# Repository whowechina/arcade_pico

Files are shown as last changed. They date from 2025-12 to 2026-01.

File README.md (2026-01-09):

# Arcade Pico - An Alternative Switch/Lamp Holder for Arcade Buttons
[点这里可以切换到中文版](README_CN.md)

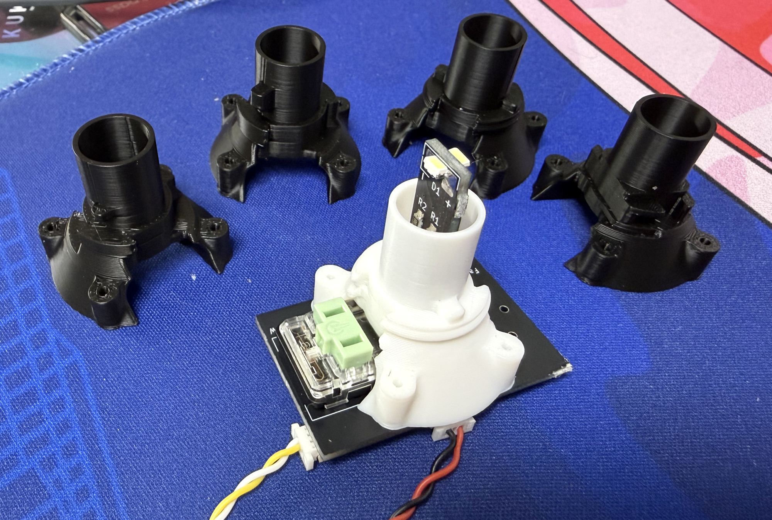
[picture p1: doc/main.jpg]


It's the successor to my sanwa_opt project. With it, you can use regular low-profile keyboard switches (or even optical sensors) on arcade buttons.

## Features
* Compatible with both old Sanwa (push-click) and new Sanwa (twist-lock), Samducksa, and common Chinese buttons;
* Supports mechanical switches, optical sensors, and magnetic switches (`IO Board` required);
* Mechanical switch can be hotswap (Kailh Choc sockets);
* Feel switch and actuation switch can be separated;
* RGB LED support (`IO Board` required);
* FDM 3D-printing friendly.
* Multiple connection options to fit different systems.

## Thanks
Thanks to many respectful guys/companies who made their tools or materials free or open source (KiCad, OnShape, InkScape, Raspberry things).

Special thanks to community projects and developers.
And also these projects:
* RP_Silicon_KiCad: https://github.com/HeadBoffin/RP_Silicon_KiCad

## My Other Projects
You can check out my other cool projects.

                

* Popn Pico: https://github.com/whowechina/popn_pico
* IIDX Pico: https://github.com/whowechina/iidx_pico
* IIDX Teeny: https://github.com/whowechina/iidx_teeny
* Chu Pico: https://github.com/whowechina/chu_pico
* Mai Pico: https://github.com/whowechina/mai_pico
* Diva Pico: https://github.com/whowechina/diva_pico
* AIC Pico: https://github.com/whowechina/aic_pico
* Groove Pico: https://github.com/whowechina/groove_pico
* Geki Pico: https://github.com/whowechina/geki_pico
* Musec Pico: https://github.com/whowechina/musec_pico
* Ju Pico: https://github.com/whowechina/ju_pico
* Bishi Pico: https://github.com/whowechina/bishi_pico
* Nos Pico: https://github.com/whowechina/nos_pico
* Voltex Pico: https://github.com/whowechina/voltex_pico
* Chord Pico: https://github.com/whowechina/chord_pico
* Arcade Pico: https://github.com/whowechina/arcade_pico

## **Disclaimer** ##
I made this project in my personal time with no financial benefit or sponsorship. I will continue to improve the project. I have done my best to ensure that everything is accurate and functional, there's always a chance that mistakes may occur. I cannot be held responsible for any loss of your time or money that may result from using this open source project. Thank you for your understanding.

## About the License
It's CC-NC. So DIY for yourself and for your friend, don't make money from it. And plagiarism that doesn’t even dare to mention the original author is not acceptable. Please note that pooling orders and group buying for raw materials is acceptable.Selling any leftover components at cost (without profit) is also acceptable.

If you're interested in buying from me, or for commercial use, please contact me (Discord, QQ group, Goofish).
* My Discord Invitation: https://discord.gg/M8f2PPQFEA
* QQ Group: 854535476
* Goofish: whowe12345

## Use Cases
### Terminology First
* **`Main Board`** - The original controller board or IO board of your arcade system.
* **`Button Board`** - The PCB that contains the switch and LED daughter board. It's the major part of the Arcade Pico project.
* **`IO Board`** - The optional PCB that converts Hall effect switch signals to digital signals, and bridges regular LED signals to WS2812B RGB LED data signals. It's also part of the Arcade Pico project. It cannot replace your original `Main Board`.
* **`Lamp Holder`** - More accurately, it's a base equipped with both lamp and switch, but commonly referred to as lamp holder.

### Case: Replace the Lamp/Switch Holder without the `IO Board`
It's the most common and easy case. The only thing you need to do is wiring the switch and LED signals from your `Main Board` to the corresponding connectors on the `Button Board`.
You can use mechanical switches or optical sensors, but you can't use magnetic switches or RGB lights.

#### Wiring:
* **SW Out** (SH1.0 3P) on `Button Board` → **Button Input** on `Main Board`
* **LED In** (SH1.0 3P) on `Button Board` ← **Lamp Output** on `Main Board`

### Case: Enjoy the Magnetic Switch or the RGB light with the `IO Board`
With magnetic switch, you can define your trigger and reset distance. With RGB light, you can define your button light color and effect. `IO Board` is required to drive the magnetic switch and RGB light.

#### Wiring:
* Magnetic switch signals
  * **SW Out** (SH1.0 3P) on `Button Board` → **Hall In** (SH1.0 3P) on `IO Board`
  * **Out** (XH2.5 2P) on `IO Board` → **Button Input** on `Main Board`
* RGB LED signals
  * **Lamp Output** on `Main Board` → **Lamp In** (XH2.5 2P) on `IO Board`
  * **LED Out** (SH1.0 3P) on `IO Board` → **LED In** (SH1.0 3P) on `Button Board`
  * **LED Out** (SH1.0 3P) on `Button Board` → **LED In** (SH1.0 3P) on next `Button Board` (if any)
  * **LED Out** (SH1.0 3P) on last `Button Board` → **LED End** (SH1.0 3P) on `IO Board` for power backup.

* You can power the `IO Board` from the `Main Board`'s 5V supply via JST 2P, or directly via Type-C port (USB or power adapter).

#### When `IO Board` is connected to a host computer via Type-C:
  * `IO Board` works as an HID device.  
    So if you're fine with this extra USB cable, you might be able to skip the wiring between the `IO Board` and the `Main Board`. However, some games require the controller to be a single device, so this won't work in those cases.
  * CLI (command line interface) is on USB CDC (serial).
  * The Type-C port is also for firmware update.

### Imagined Case: Interfacing with DJDao PhoenixWAN
This is a theoretical case that probably won't be implemented. If implemented, all that cockamamie wiring between `IO Board` and `Main Board` would be eliminated - they'd simply communicate via UART.

Let's hope this happens someday.

# How to Build
## The Button Board
### Common Part
* The PCB gerber file is `Production/PCB/"arcade_pico_button_*.zip`. The one with `socket` is hotswap (for Choc V1 and V2). I always use JLC (https://www.jlcpcb.com) and Jiepei (https://www.jiepei.com), feel free to use your preferred PCB manufacturer. They may ask if you need half-hole pads for the `Button Board`, just answer "No", it's costy and not necessary.
* 2X 3P SH1.0 horizontal SMD connector on "SW" and "LED In" footprints.
* 1X 3P SH1.0 horizontal SMD connector on "LED Out" footprint, only needed when using WS2812B RGB LED daughter board.

* To connect LEDs:
  * "LED In" connector (+, -) is for regular single color LED signal from your existing `Main Board`.
  * "LED In" and "LED Out" connectors are for daisy-chain when using WS2812B RGB LED daughter board.

### Mechanical Switch
* Use either SW1 or SW2 footprint for Kailh Choc V1/V2 switches.
* Use Kailh Choc low-profile hotswap socket if you choose hotswap PCB version.  
  https://kailhswitch.net/products/kailh-mechnical-keyboard-switches-hot-swap-pcb-socket-diy-for-1350-choc-low-profile-keyboard-switches
* Short the corresponding jumper (sw1 or sw2) to enable the switch.
* You can solder the other switch, but it's only for the feel, so don't short the jumper.

* To connect to controller's `Main Board`:
  * "SW" connector (Out, GND) is for the switch signal;

* This example shows SW1 as the trigger switch, and optional Choc V1 on SW2 is just for the feel.  
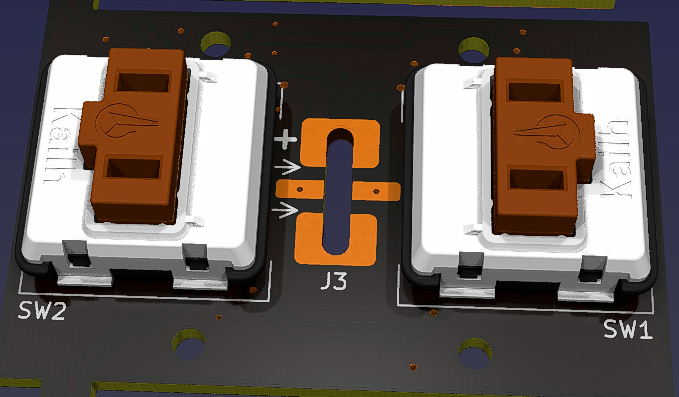
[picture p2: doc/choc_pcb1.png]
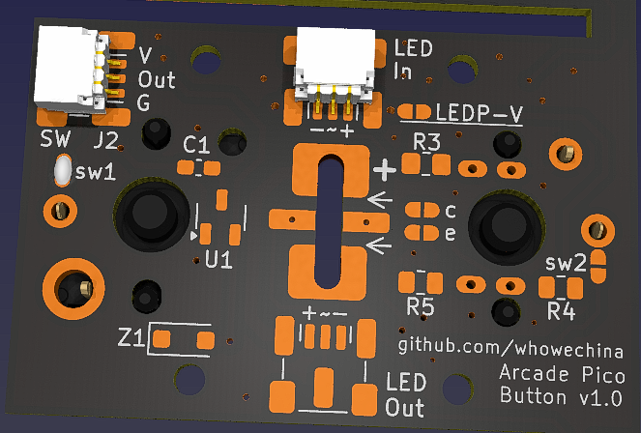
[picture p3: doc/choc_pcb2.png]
   

### Optical Sensor (IR Diode + Phototransistor)
* Solder the IR diode (IR908-7C) and phototransistor (PT908-7C) at proper height;
* Solder R3 (500 ohm for 3.3V supply, 1k ohm for 5V supply);
* Resistors: R4, R5; Jumpers: c, e; Zener: Z1.
  * Low-active logic (most systems are): R4 (0-10 ohm), R5 (2k ohm), short the jumper e by soldering.
  * High-active logic: R4 (2k ohm), R5 (0-10 ohm), short the jumper c.
  * When power supply is 5V but the target system IO is 3.3V, solder Z1 (3.3V SOD-123F Zener diode) to protect the IO pin.
* You can solder a mechanical switch on SW1 footprint for some tactile feel, but don't short the jumper sw1.
* On most systems, LED positive line is a constant 5V or 3.3V power supply, you can borrow that to power the optical sensor - just short the jumper "LEDP-V".

* To connect to controller's `Main Board`:
  * "SW" connector (V, Out, GND) is for the switch signal;

* This example shows a low-active configuration, 5V is borrowed from LED positive line, and optional Choc V1 on SW1 just for the feel.  
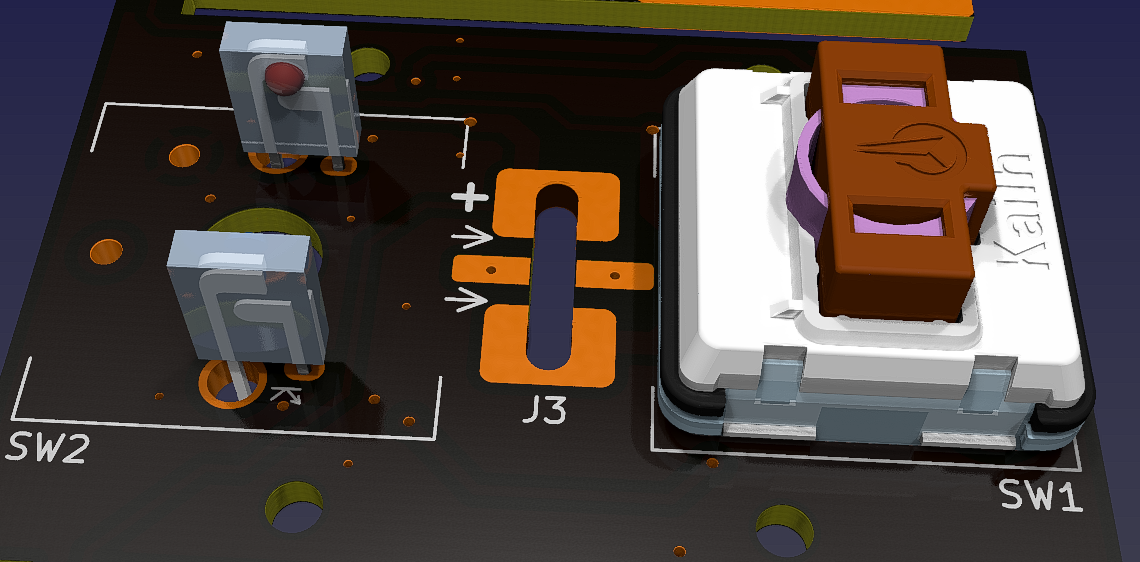
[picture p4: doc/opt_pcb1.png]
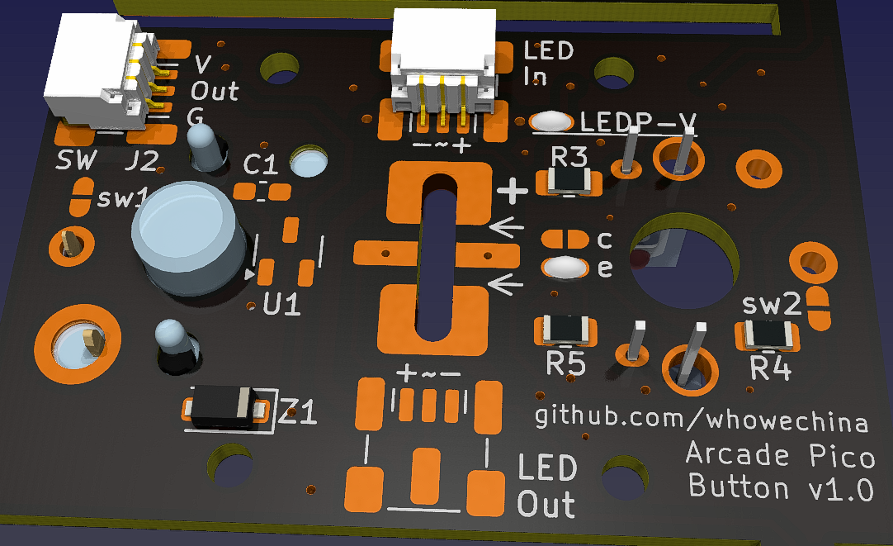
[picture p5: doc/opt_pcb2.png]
   

### Magnetic (Hall Effect) Switch
* Magnetic switch is on SW1 footprint.
* Solder U1 (SS49E SOT23-3) and C1 (0.1uF 0603).
* You can install a mechanical switch on SW2 footprint for some tactile feel, but don't solder the jumper.
* If the Hall effect switch is not mounted tightly, you may need to use some RTV silicone adhesive to secure it.

* This example uses Hall effect switch on SW2 and optional Choc V1 on SW1 just for the feel.  
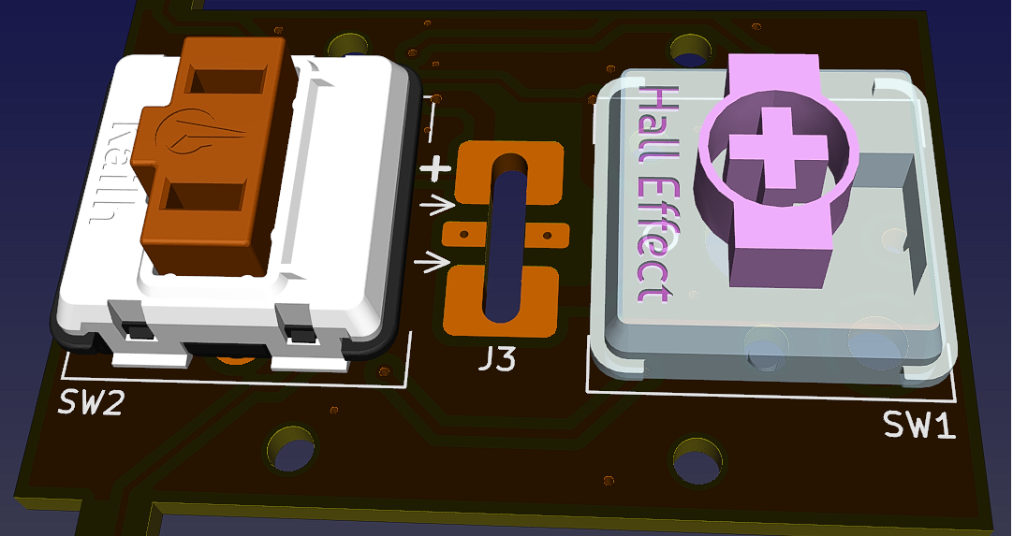
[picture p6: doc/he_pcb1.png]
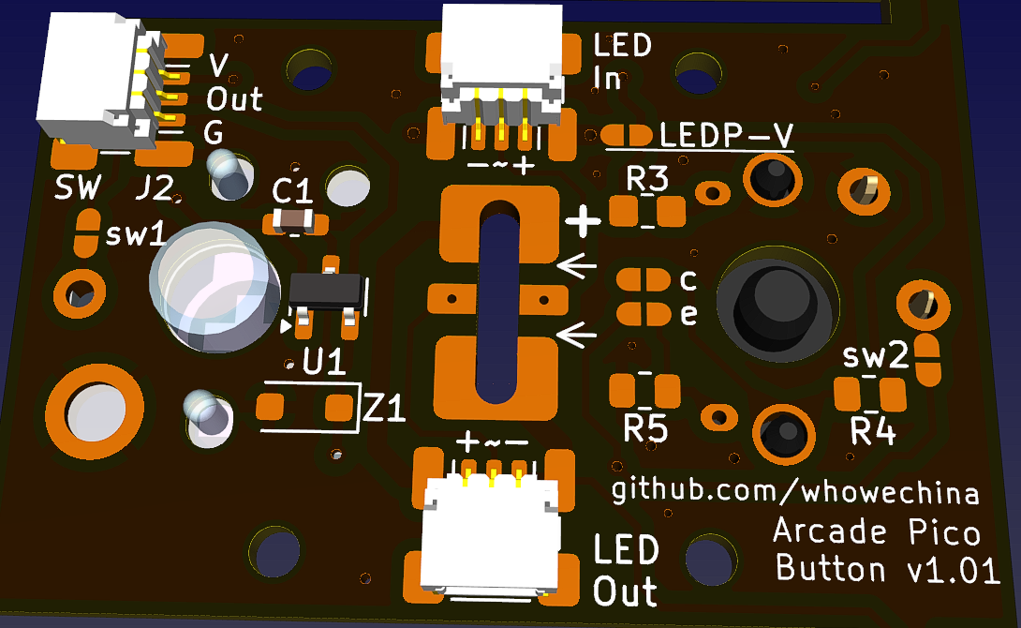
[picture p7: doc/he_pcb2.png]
   

* To connect to controller's `Main Board`:
* "SW" connector (V, Out, G) connects to the **Arcade Pico IO** board. Then the `IO Board` connects to the `Main Board`.

* Note that Arcade Pico `IO Board` is need for this setup.

## The LED Daughter Board
* It is separated from the **Arcade Pico Button** board by snapping or cutting. There're two versions: single-color LED and WS2812B RGB LED. You can choose either one according to your needs.
* After soldering the components, insert the LED daughter board back to the button PCB vertically from the top side. Solder one pin first, so you'll have a chance to adjust the height.
* If it's too low or too high, you won't get even illumination. You can measure the height from your old lamp holder. From my experience with Sanwa, distance from the LED top to the PCB surface is about 37mm.
* When you finish adjusting the height, solder all pins to secure the connection.  
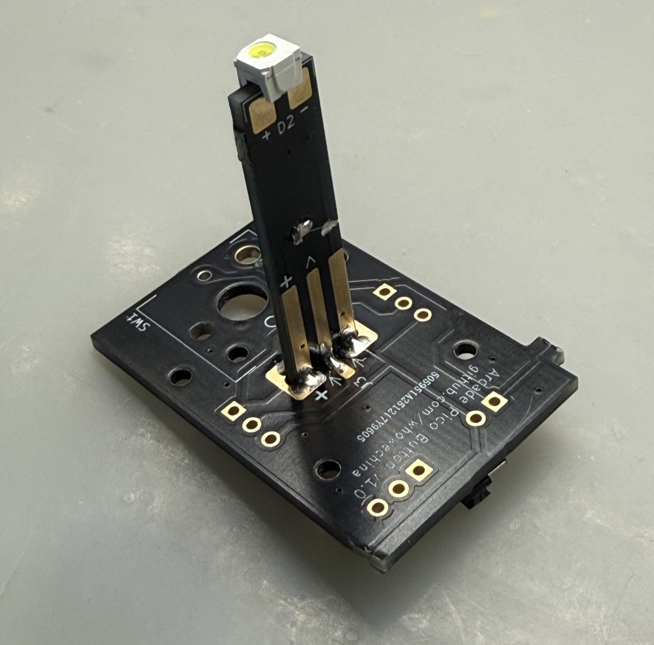
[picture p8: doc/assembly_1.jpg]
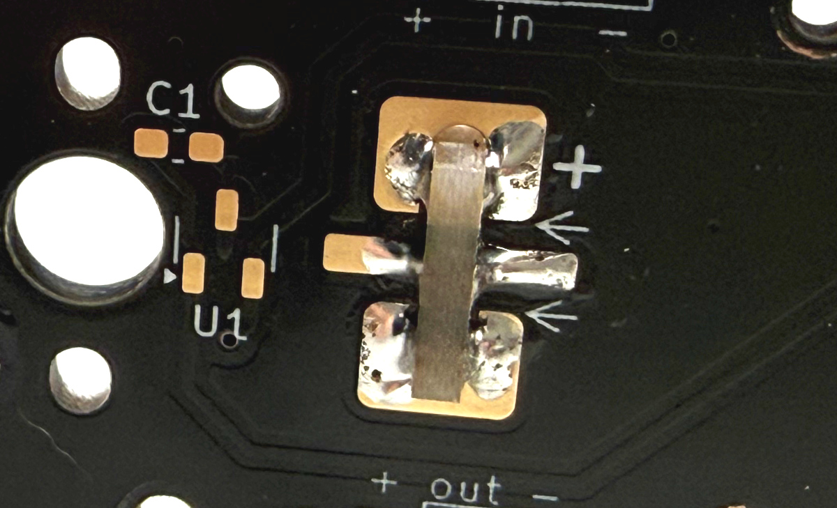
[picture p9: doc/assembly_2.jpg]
 

### Single-color LED Board
* Use high-brightness side emitting LEDs. The footprint is compatible with various packages, such as SMD 4008, SMD 4020, SMD 3014, or even through-hole ones (ones with concave lens are better).
* If you're using SMD LEDs, you can use two of them, one for each side, to get better light distribution.
* They're normally rated for 20mA current. So typically you use 100-220 ohm current resistors (R1 and R2) for 5V supply, or 50-100 ohm for 3.3V supply.
* Here's how it looks after soldered.  
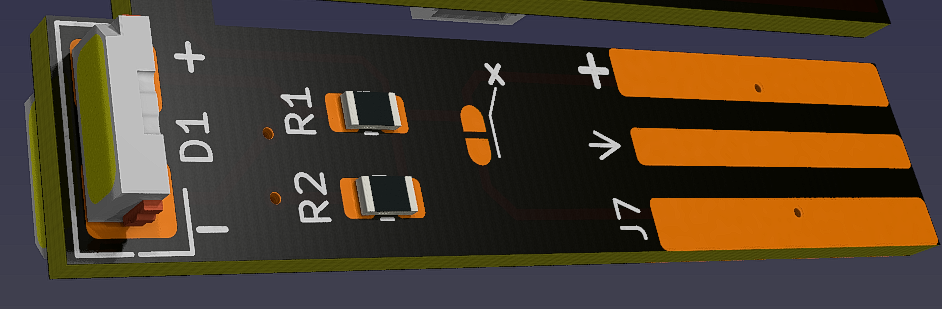
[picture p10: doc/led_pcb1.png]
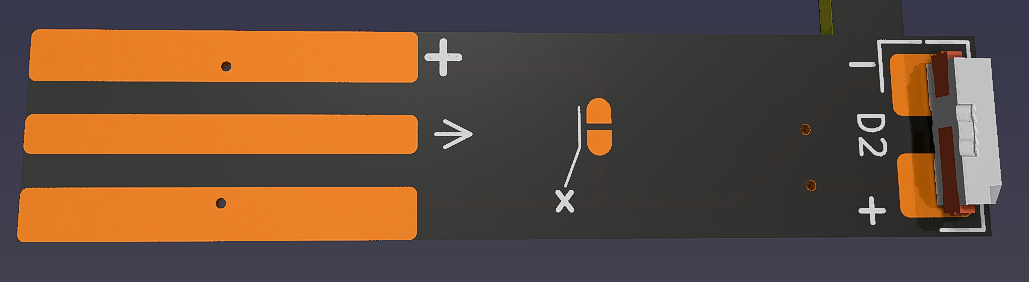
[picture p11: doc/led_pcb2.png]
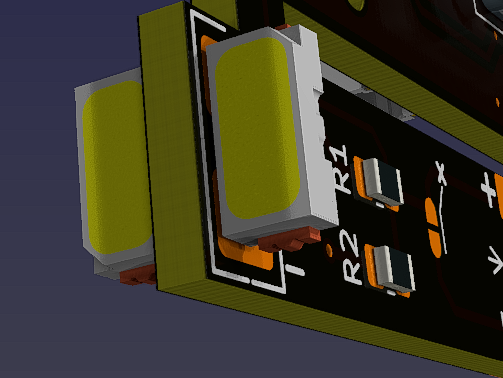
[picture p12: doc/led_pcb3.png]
    
* If the polarity of the LED footprint doesn't match your LED, just cut/break the copper trace right at the "x" mark at **both sides**, and short the jumpers accordingly. This will reverse the polarity.  
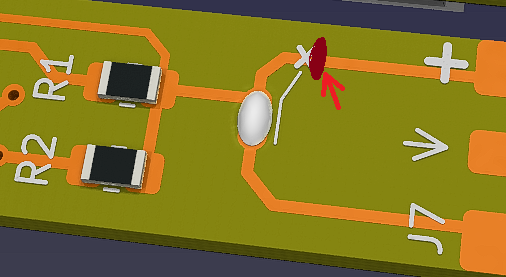
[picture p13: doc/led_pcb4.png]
  

### WS2812B RGB LED Board
* **Arcade Pico `IO Board` is required.**
* Use WS2812B 4020 side emitting RGB LEDs. You can use two of them, one for each side, to get better light distribution.
* 0.1uF 0805 or 0603 capacitor on C2 footprint is highly recommended.
* Here's how it looks after soldered.  
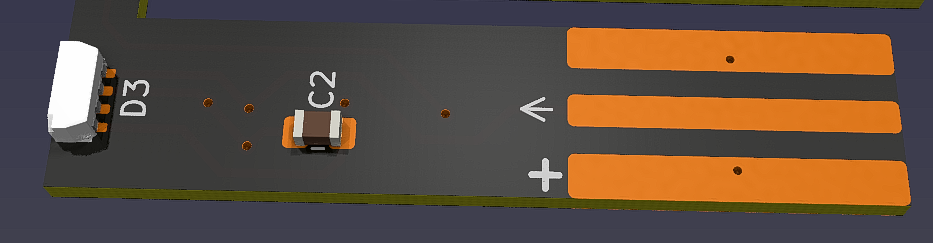
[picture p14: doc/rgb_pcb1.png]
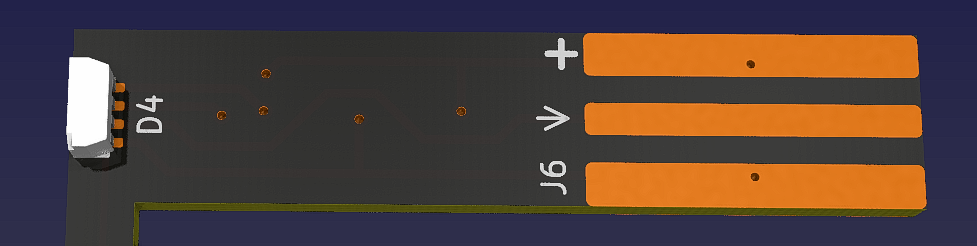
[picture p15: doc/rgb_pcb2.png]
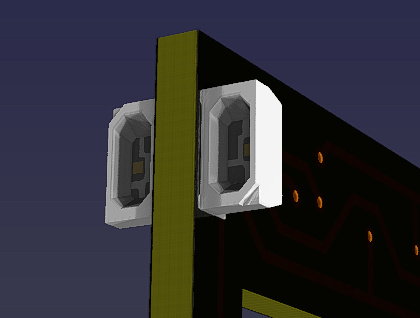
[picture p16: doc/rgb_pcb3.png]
    

## The `IO Board`
* The `IO Board` can convert the analog signals from Hall effect switches into digital signals for your main controller board. It can also bridge traditional LED bulb signals to WS2812B RGB LED data signals.
* If you don't need one or both of these functions, just skip the corresponding components.

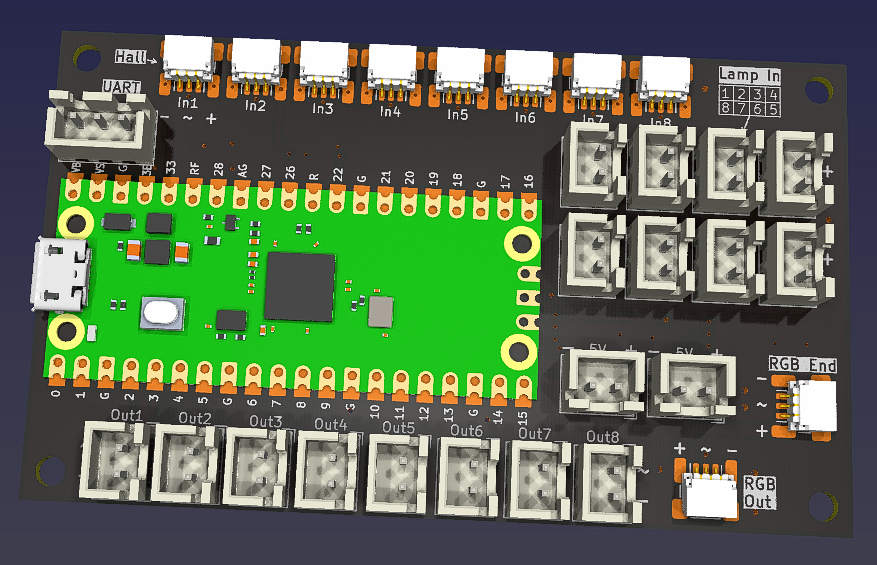
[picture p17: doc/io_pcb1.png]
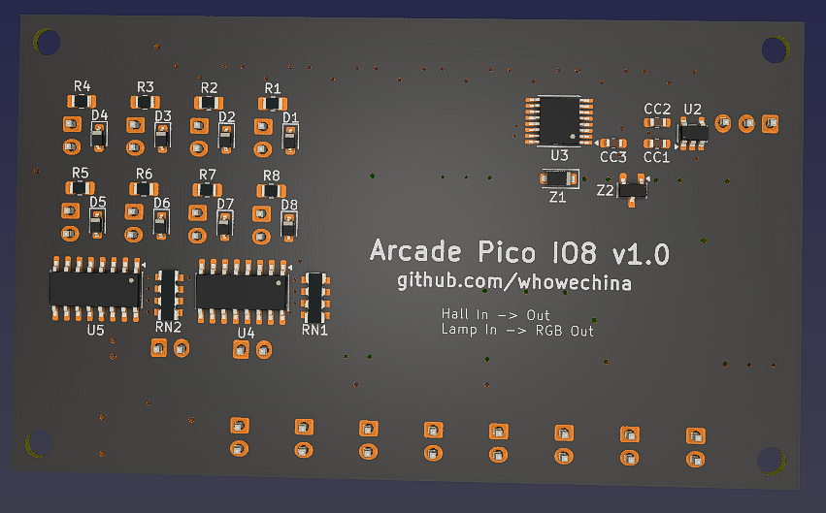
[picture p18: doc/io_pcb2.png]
 

### Common Parts
* 1x Raspberry Pi Pico.  
  https://www.raspberrypi.com/products/raspberry-pi-pico
* 2x 2P JST XH2.54 or XH2.5 vertical connectors, for 5V power input.
* 1x 3P JST XH2.54 or XH2.5 vertical connector for UART, optional for future use.

### Components for Hall Effect Switch
* 1x ADG708BRUZ, 8 to 1 analog switch, in TSSOP-16 (U3).
* 1x LP5907MFX-4.5 or TPS7A2042PDBVR LDO, in SOT23-5 (U2), see next line.
* 1x LM4040 shunt voltage reference in SOT23-3 (Z2), 2.0~2.1V (for 4.2V LDO) or 2.2~2.5V (for 4.5V LDO).
* 1x 3.3V Zener diode, in SOD-123 or SOD-123F, such as BZT52H-C3V3 (Z1).
* 3x 0.1uF 0603 capacitors (CC1, CC2, CC3).
* 8x 3P SH1.0 horizontal SMD connectors (In1~In8), for connecting up to 8 Hall effect `Button Board`s.
* 8x 2P JST XH2.54 or XH2.5 vertical connectors (Out1~Out8), for connecting to the main controller board.

### Components for RGB LED
* 8x 220ohm 0603 resistors (R1~R8), for optical isolator current limiting. If your light is 12V, use 1kohm 0805 resistors instead.
* 8x 1N4148 SOD-323 diodes (D1~D8), to protect from reverse voltage, only needed for 12V light input.
* 2X PC847 or compatible quad optical isolators (U4, U5), in SOP-16.
* 2x 0805 x 4 5.1K 8P4R resistor arrays (RN1, RN2), if they're not available, use 8x individual 5.1K 0603 resistors instead.
* 2x 3P SH1.0 horizontal SMD connectors (LED Out and LED End), to connect to the `Button Board` equipped with WS2812B RGB LED daughter board.
* 8x 2P JST XH2.54 or XH2.5 vertical connectors (Lamp In 1~8), for connecting to the main controller board's LED signal.

## Notes on PCB and Electronics
### Things You May **Need** to Tinker with
* Here's how you calculate the LED current limiter, it also applies to the IR emitter diode of the optical isolator:
  * R = (V_supply - V_F) / I
  * V_F for single color LED is usually around 3V, V_F for IR emitter is usually around 1.3V.
  * I for single color LED is usually 10-20mA, I for IR emitter is practically 1-10mA.
* Here's how you calculate the pull-up or pull-down resistor for phototransistor (the one on the `Button Board` and the one inside the optical isolator):
  * R >= V_supply / I_C
  * It's difficult to estimate the I_C (collector current) of the phototransistor, so just assume it's around 1mA.
  * So on a 3.3V power supply, R >= 3.3V / 1mA = 3.3K ohm, You can use a 3.3K or 3.9K ohm resistor.
  * You may need to adjust the resistor value according to your actual setup.

### Things You May **Want** to Tinker with
* For the "feel switch", choose clicky ones, Choc V1 and Choc V2 both have some clikcy options. If you find other low-profile mechanical switches which fit in the footprint, you can try them too.
* When Hall effect switch and the "feel" switch is both installed, spring force adds up, you may want to use a lighter spring for both of them. You can choose light force switches, or you can change the spring inside them.

## The Holder Body
* Use any FDM printer to print the body.
  * Material: PLA, PETG, ABS, you name it.
  * Layer Height: 0.2mm is recommended.
  * Infill: 20% is enough.
  * Walls: 2-4 perimeters.
  * Support: Yes, tree support.

* Files are in the "Production/3DPrint" folder.
  * `Sanwa_push.stl` - old style Sanwa lamp holder (push-click type).
  * `Sanwa_twist.stl` - new style Sanwa lamp holder (twist-lock type).
  * `Samducksa.stl` - Samducksa lamp holder.
  * `Chinese.stl` - common Chinese button lamp holder.

* Use M2\*6mm screws to secure the PCB to the button.

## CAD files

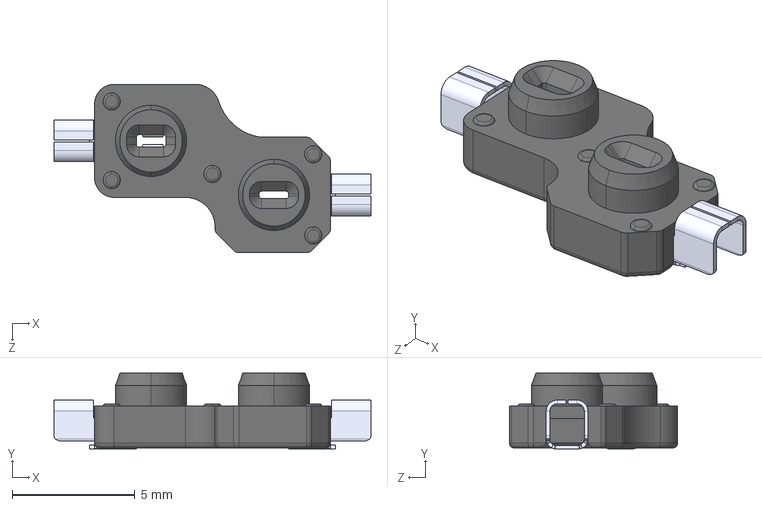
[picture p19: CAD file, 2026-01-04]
PCB/button_dip_led/3dmodels/PG1350-socket.STEP
12.9 x 3.09 x 6.85 mm
pin x 2
socket

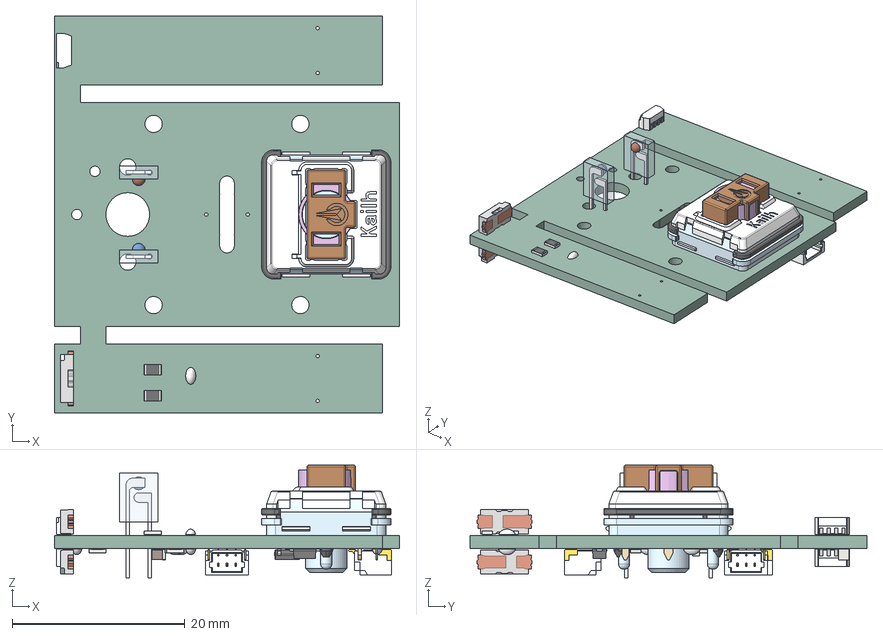
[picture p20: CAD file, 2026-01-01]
PCB/button_dip_led/button_pcb_v1.0.step
40.0 x 46.0 x 13.1 mm
LUXEON_3014 x 2
User Library-WS2812-4020 x 2
SW_Kailh_Choc_V1
Kailh_PG1352 x 3
Lens
LeadA
LeadB
LensPT
Mirrored LeadA
Mirrored LeadB
SolderJump x 7
R_0805_2012Metric x 5
SM3B-SRSS-TB x 3
C_0603_1608Metric
SOT-23-3
C_0805_2012Metric
D_SOD-123F
button_PCB

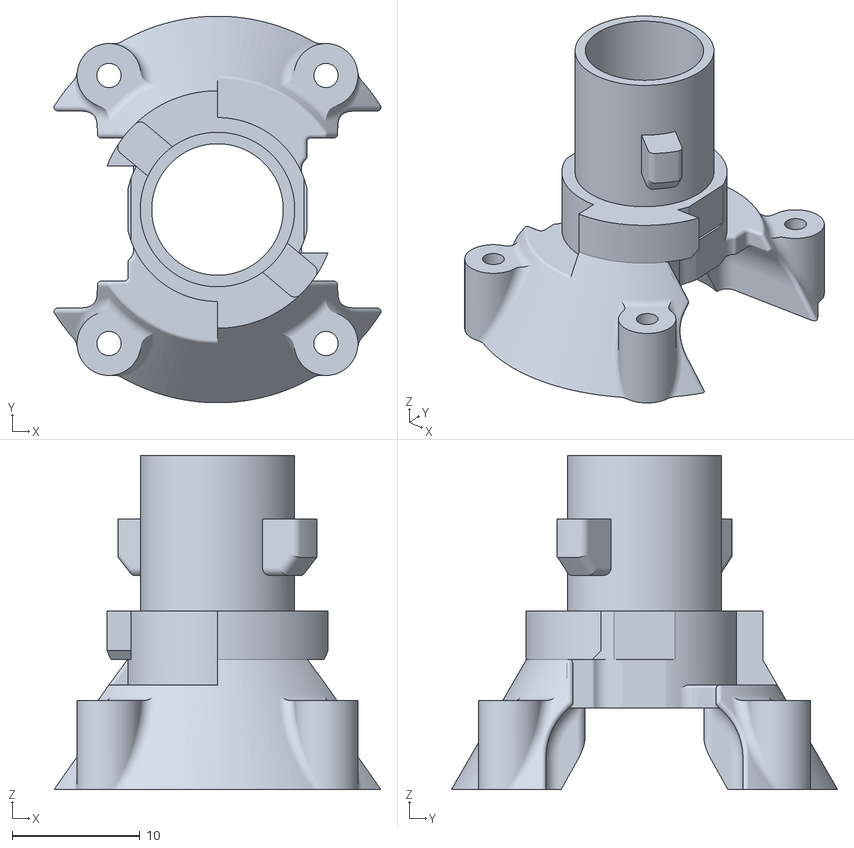
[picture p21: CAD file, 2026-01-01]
Production/3DPrint/Sanwa_twist.stl
25.6 x 30.3 x 26.2

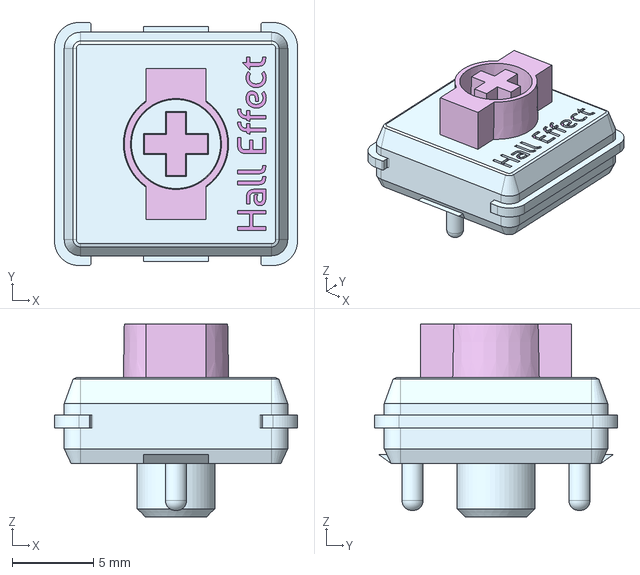
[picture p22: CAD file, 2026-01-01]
PCB/button_dip_led/3dmodels/HE_PG1353.step
15.0 x 15.0 x 11.9 mm

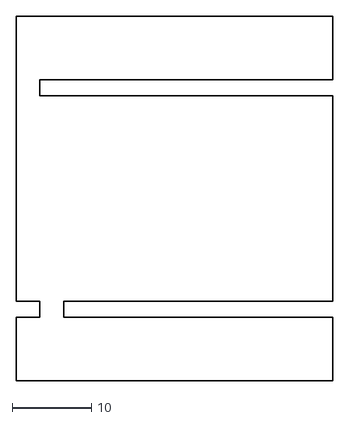
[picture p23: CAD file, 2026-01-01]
PCB/button_dip_led/Arcade Pico - PCB EdgeCut.dxf
40.0 x 46.0

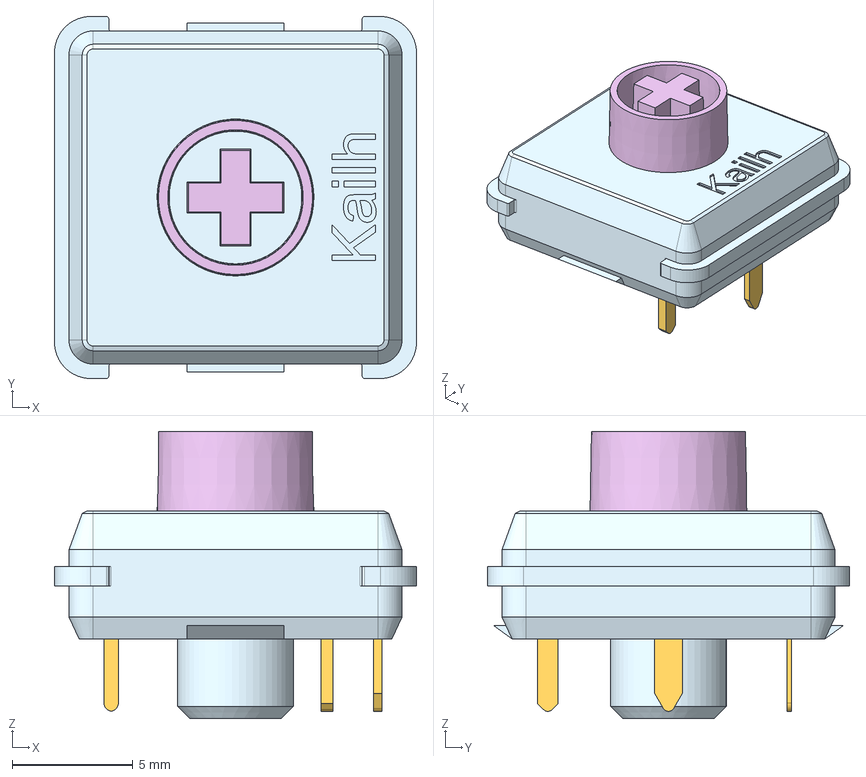
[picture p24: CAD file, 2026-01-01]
PCB/button_dip_led/3dmodels/Kailh_PG1353.STEP
15.0 x 15.0 x 11.9 mm

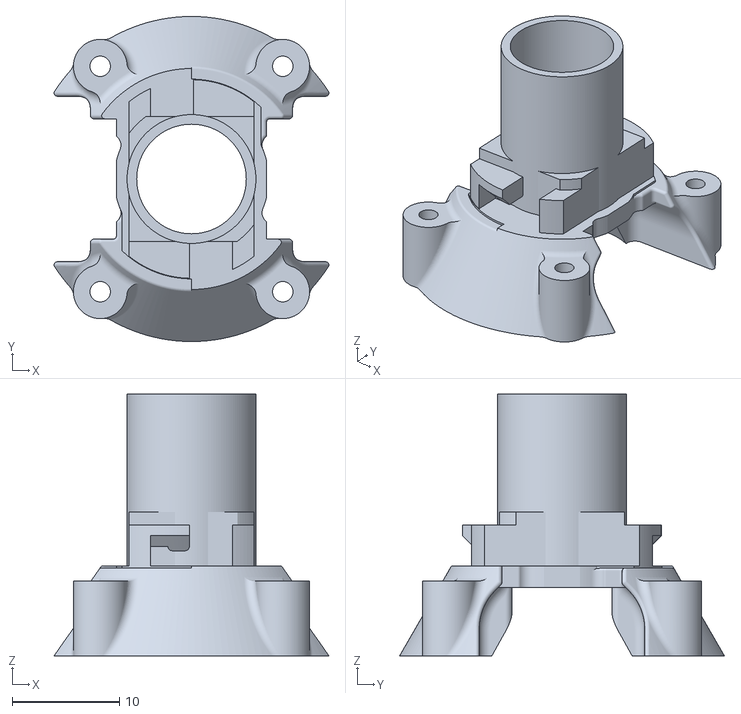
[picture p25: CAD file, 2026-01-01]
Production/3DPrint/Chinese.stl
25.6 x 30.3 x 24.4

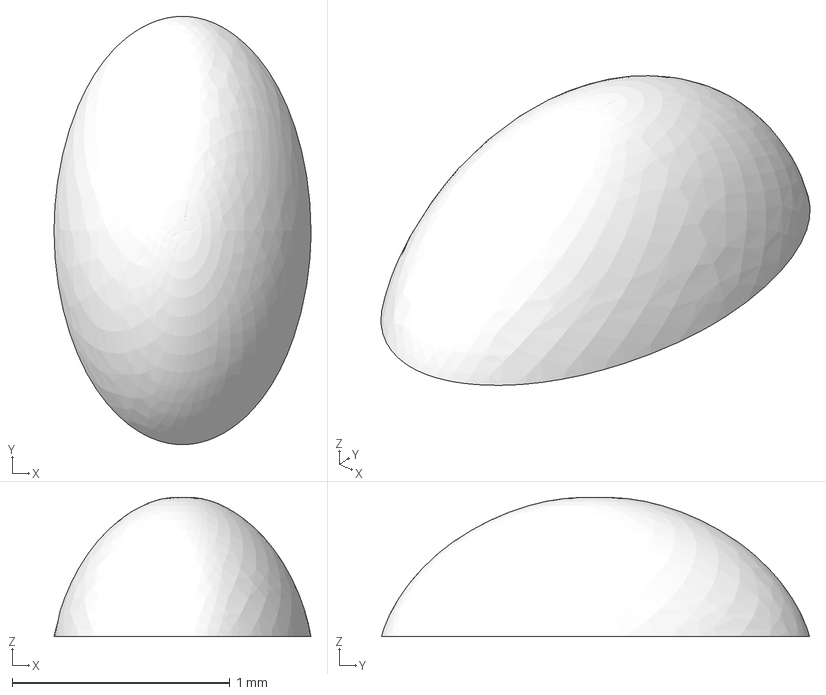
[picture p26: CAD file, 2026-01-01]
PCB/button_dip_led/3dmodels/SolderJump.step
1.18 x 1.97 x 0.64 mm

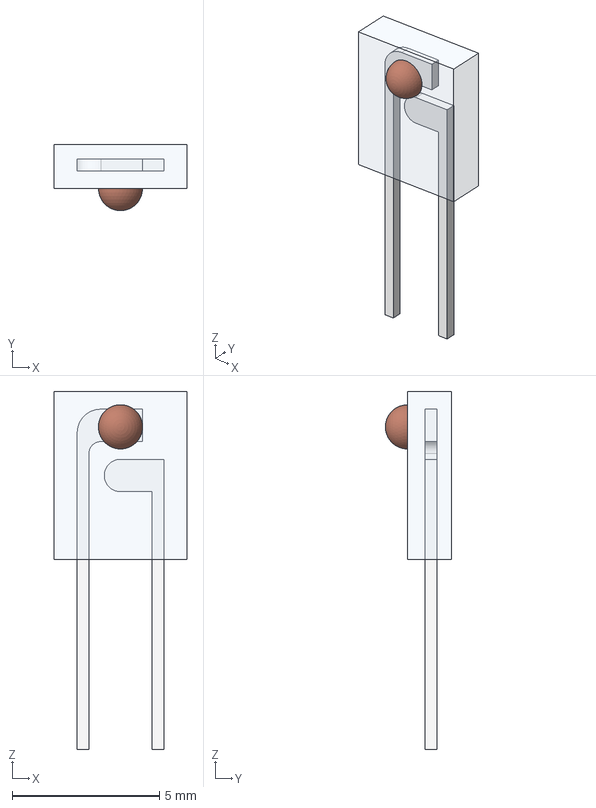
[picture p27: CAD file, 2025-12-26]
PCB/button_dip_led/3dmodels/IR908-7C.step
4.50 x 2.25 x 12.2 mm

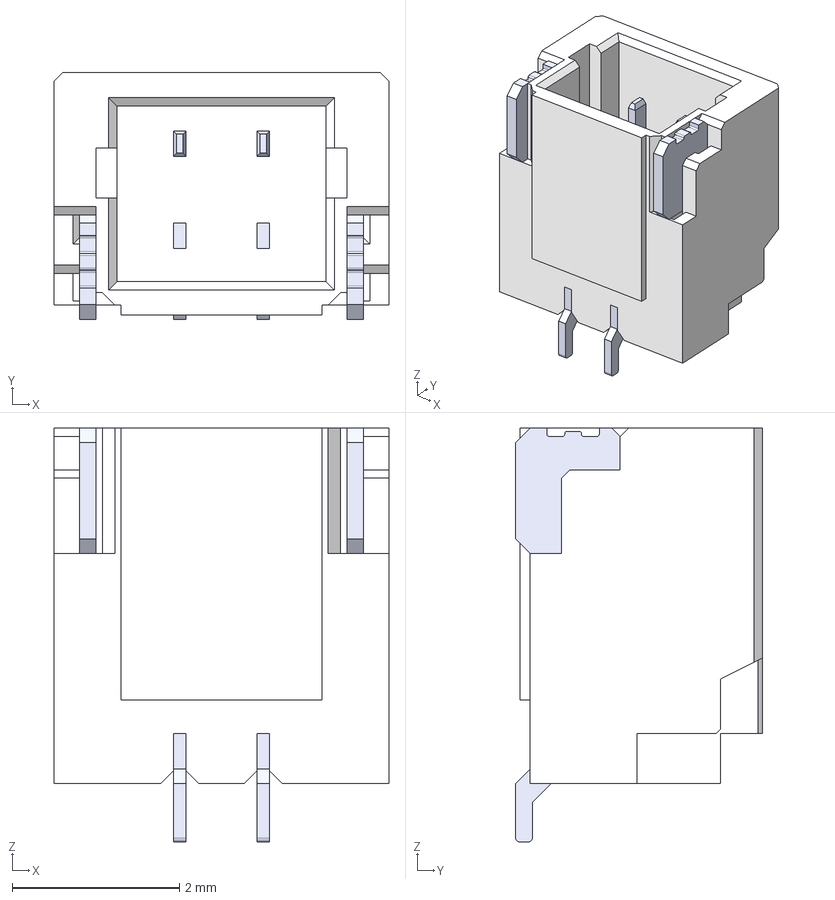
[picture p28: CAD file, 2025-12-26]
PCB/button_dip_led/3dmodels/SM2B-SRSS-TB.step
4.00 x 2.95 x 4.95 mm

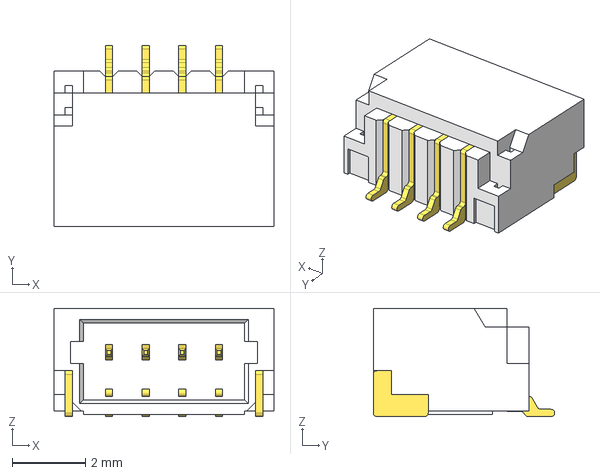
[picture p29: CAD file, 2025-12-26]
PCB/button_dip_led/3dmodels/SM4B-SRSS-TB.step
6.00 x 4.95 x 2.95 mm

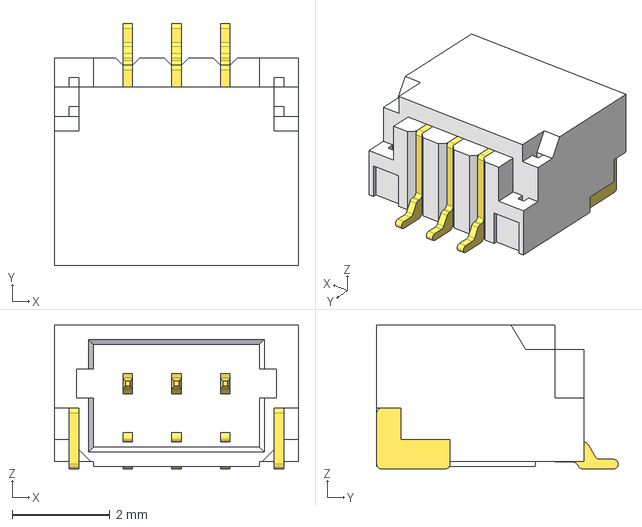
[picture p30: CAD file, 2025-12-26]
PCB/button_dip_led/3dmodels/SM3B-SRSS-TB.step
5.00 x 4.95 x 2.95 mm

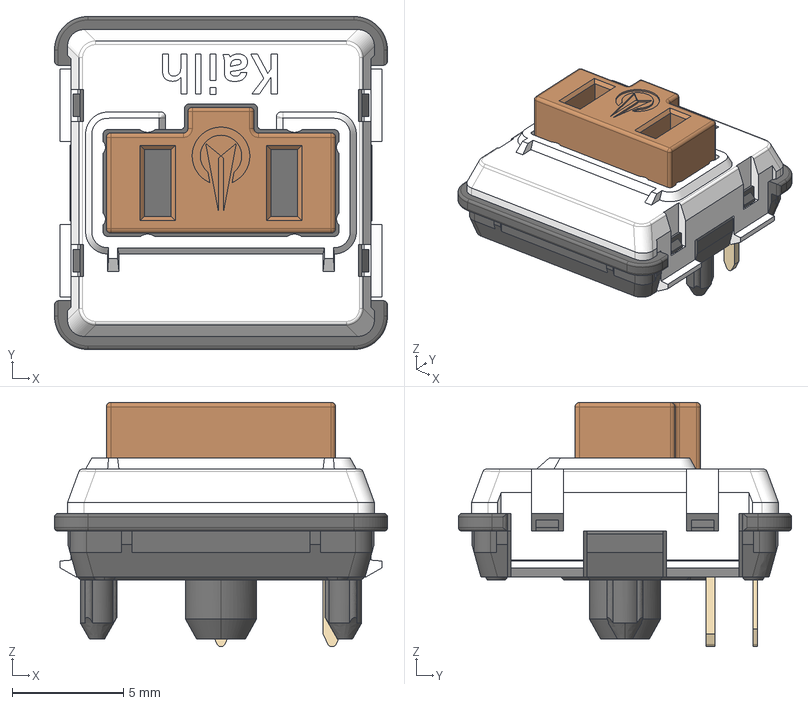
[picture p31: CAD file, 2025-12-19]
PCB/button_dip_led/3dmodels/SW_Kailh_Choc_V1.stp
15.0 x 15.0 x 11.0 mm

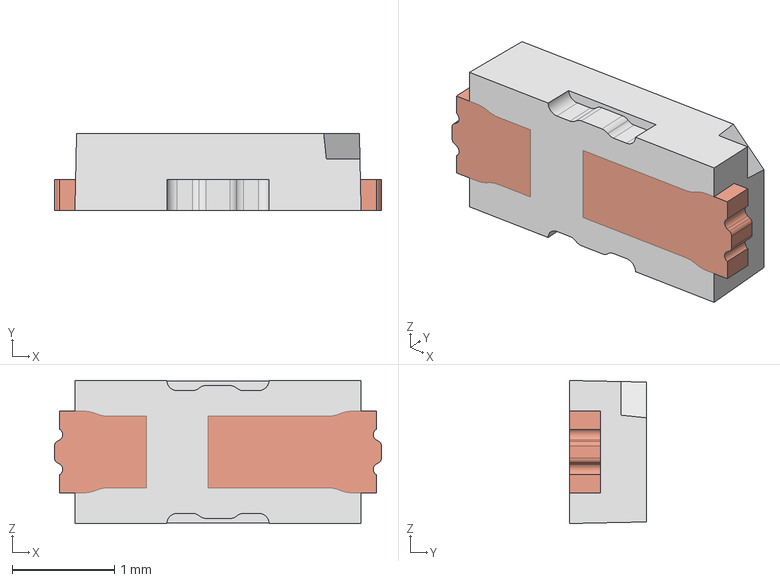
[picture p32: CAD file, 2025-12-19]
PCB/button_dip_led/3dmodels/LUXEON_3014.stp
3.20 x 0.75 x 1.40 mm

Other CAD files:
Production/3DPrint/Sanwa_push.stl
PCB/button_dip_led/3dmodels/PT908-7C.step
PCB/button_dip_led/3dmodels/User Library-WS2812-4020.step

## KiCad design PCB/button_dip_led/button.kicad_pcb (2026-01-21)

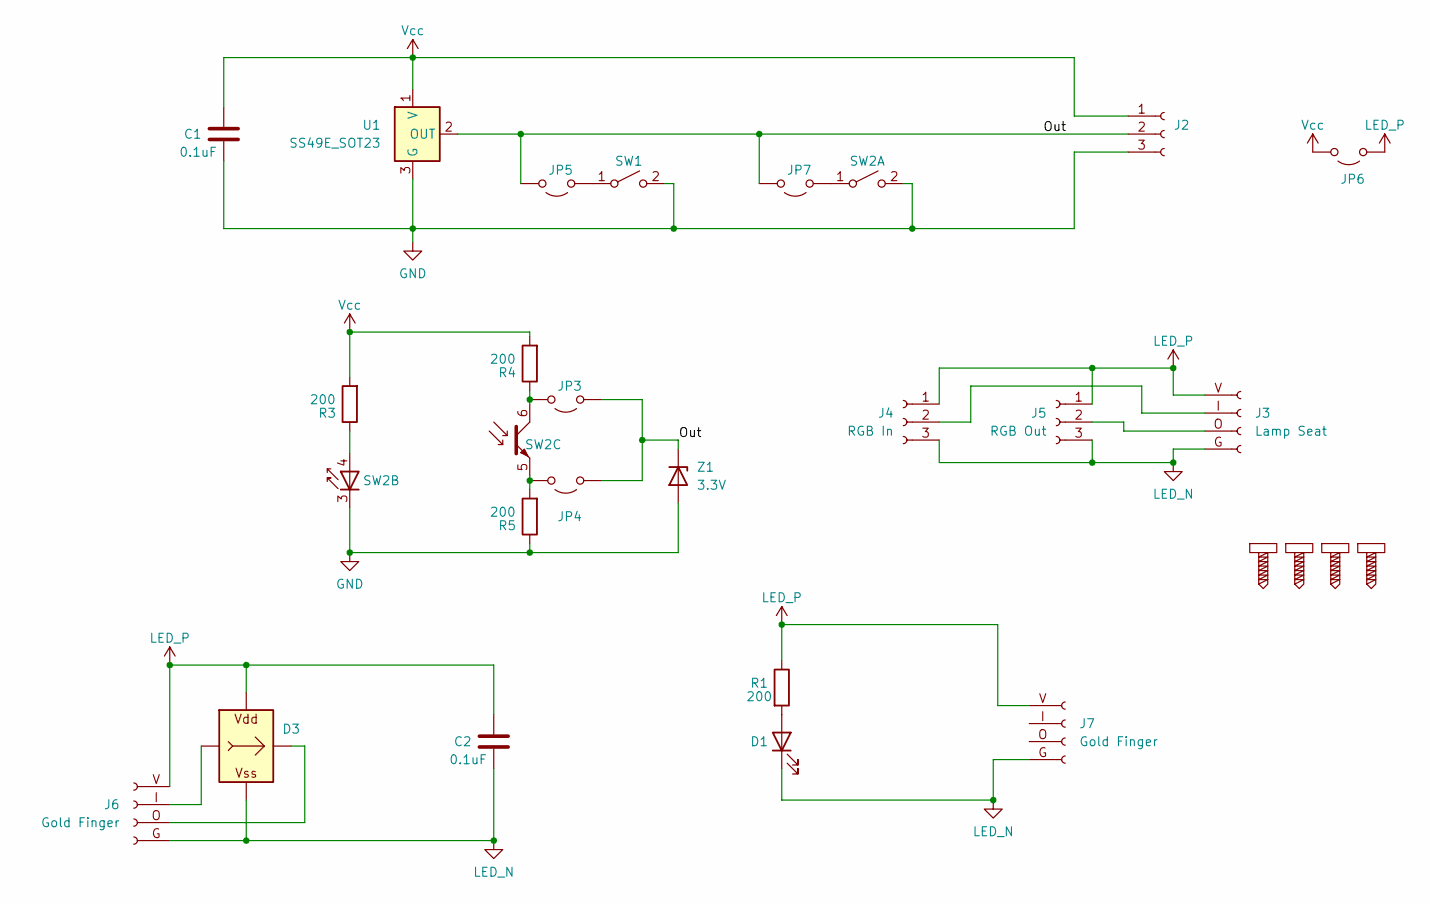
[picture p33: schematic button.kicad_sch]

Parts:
C1: 0.1uF; C_0603_1608Metric_Pad1.08x0.95mm_HandSolder
C2: 0.1uF; C_0805_2012Metric_Pad1.18x1.45mm_HandSolder
D1: LED; DIPLED
D3: WS2812B_Unified; WS2812B-DIP
J2: Conn_01x03_Socket; SH1.0_3P_Solder_Combo
J3: Lamp Seat; LampSeat
J4: RGB In; SH1.0_3P_Solder_Combo
J5: RGB Out; SH1.0_3P_Solder_Combo
J6, J7: Gold Finger; GoldFinger
JP3: c; SolderJump
JP4: e; SolderJump
JP5: sw1; SolderJump
JP6: LEDP-V; SolderJump
JP7: sw2; SolderJump
R1, R3: 200; R_0805_2012Metric_Pad1.20x1.40mm_HandSolder
R4, R5: 200; R_0805_2012Metric
S1, S2, S3, S4: M2_Screw
SW1: Choc_HE
SW2: Choc and IR Pair; SW_Kailh_Choc_IR_Combo
U1: SS49E_SOT23; SOT-23-FAT
Z1: 3.3V; D_SOD-123F

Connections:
/Out: J2.2, JP3.1 (A), JP4.1 (A), JP5.2 (B), JP7.2 (B), U1.2 (OUT), Z1.1 (K)
GND: C1.1, J2.3, R5.1, SW1.2 (B), SW2.2 (B), SW2.3 (K), U1.3 (G), Z1.2 (A)
LED_N: C2.1, D1.1 (K), D3.G (VSS), J3.G, J4.3, J5.3, J6.G, J7.G
LED_P: C2.2, D3.V (VDD), J3.V, J4.1, J5.1, J6.V, J7.V, JP6.1 (A), R1.1
unnamed: D1.2 (A), R1.2
unnamed: D3.I (In), J6.I (In)
unnamed: D3.O (Out), J6.O (Out)
unnamed: J3.I (In), J4.2
unnamed: J3.O (Out), J5.2
unnamed: JP3.2 (B), R4.1, SW2.6 (C)
unnamed: JP4.2 (B), R5.2, SW2.5 (E)
unnamed: JP5.1 (A), SW1.1 (A)
unnamed: JP7.1 (A), SW2.1 (A)
unnamed: R3.1, SW2.4 (A)
Vcc: C1.2, J2.1, JP6.2 (B), R3.2, R4.2, U1.1 (V)

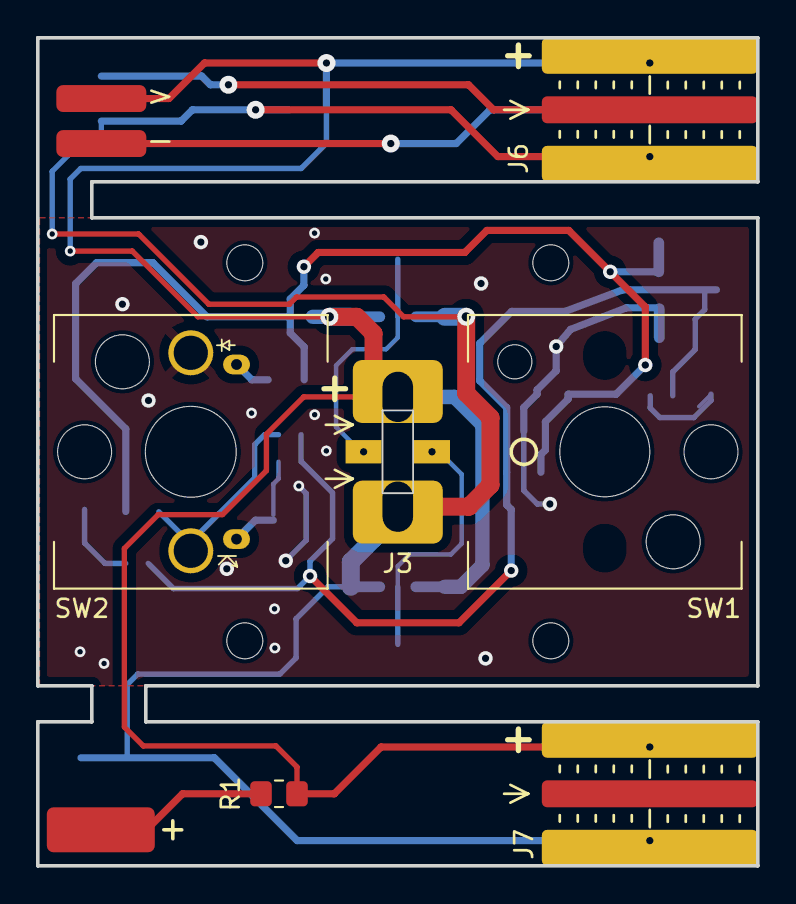
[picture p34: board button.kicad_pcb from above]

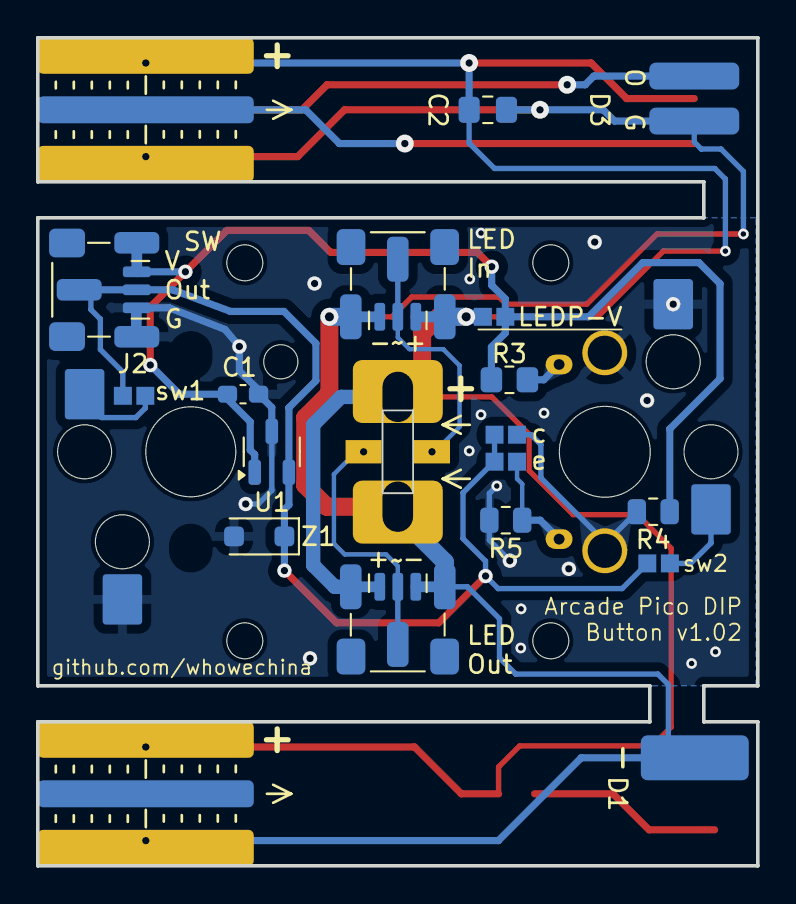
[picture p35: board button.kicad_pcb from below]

Board: 2 copper layers, 40.0 x 46.0 mm, 27 parts (17 on the bottom side), 15 nets.

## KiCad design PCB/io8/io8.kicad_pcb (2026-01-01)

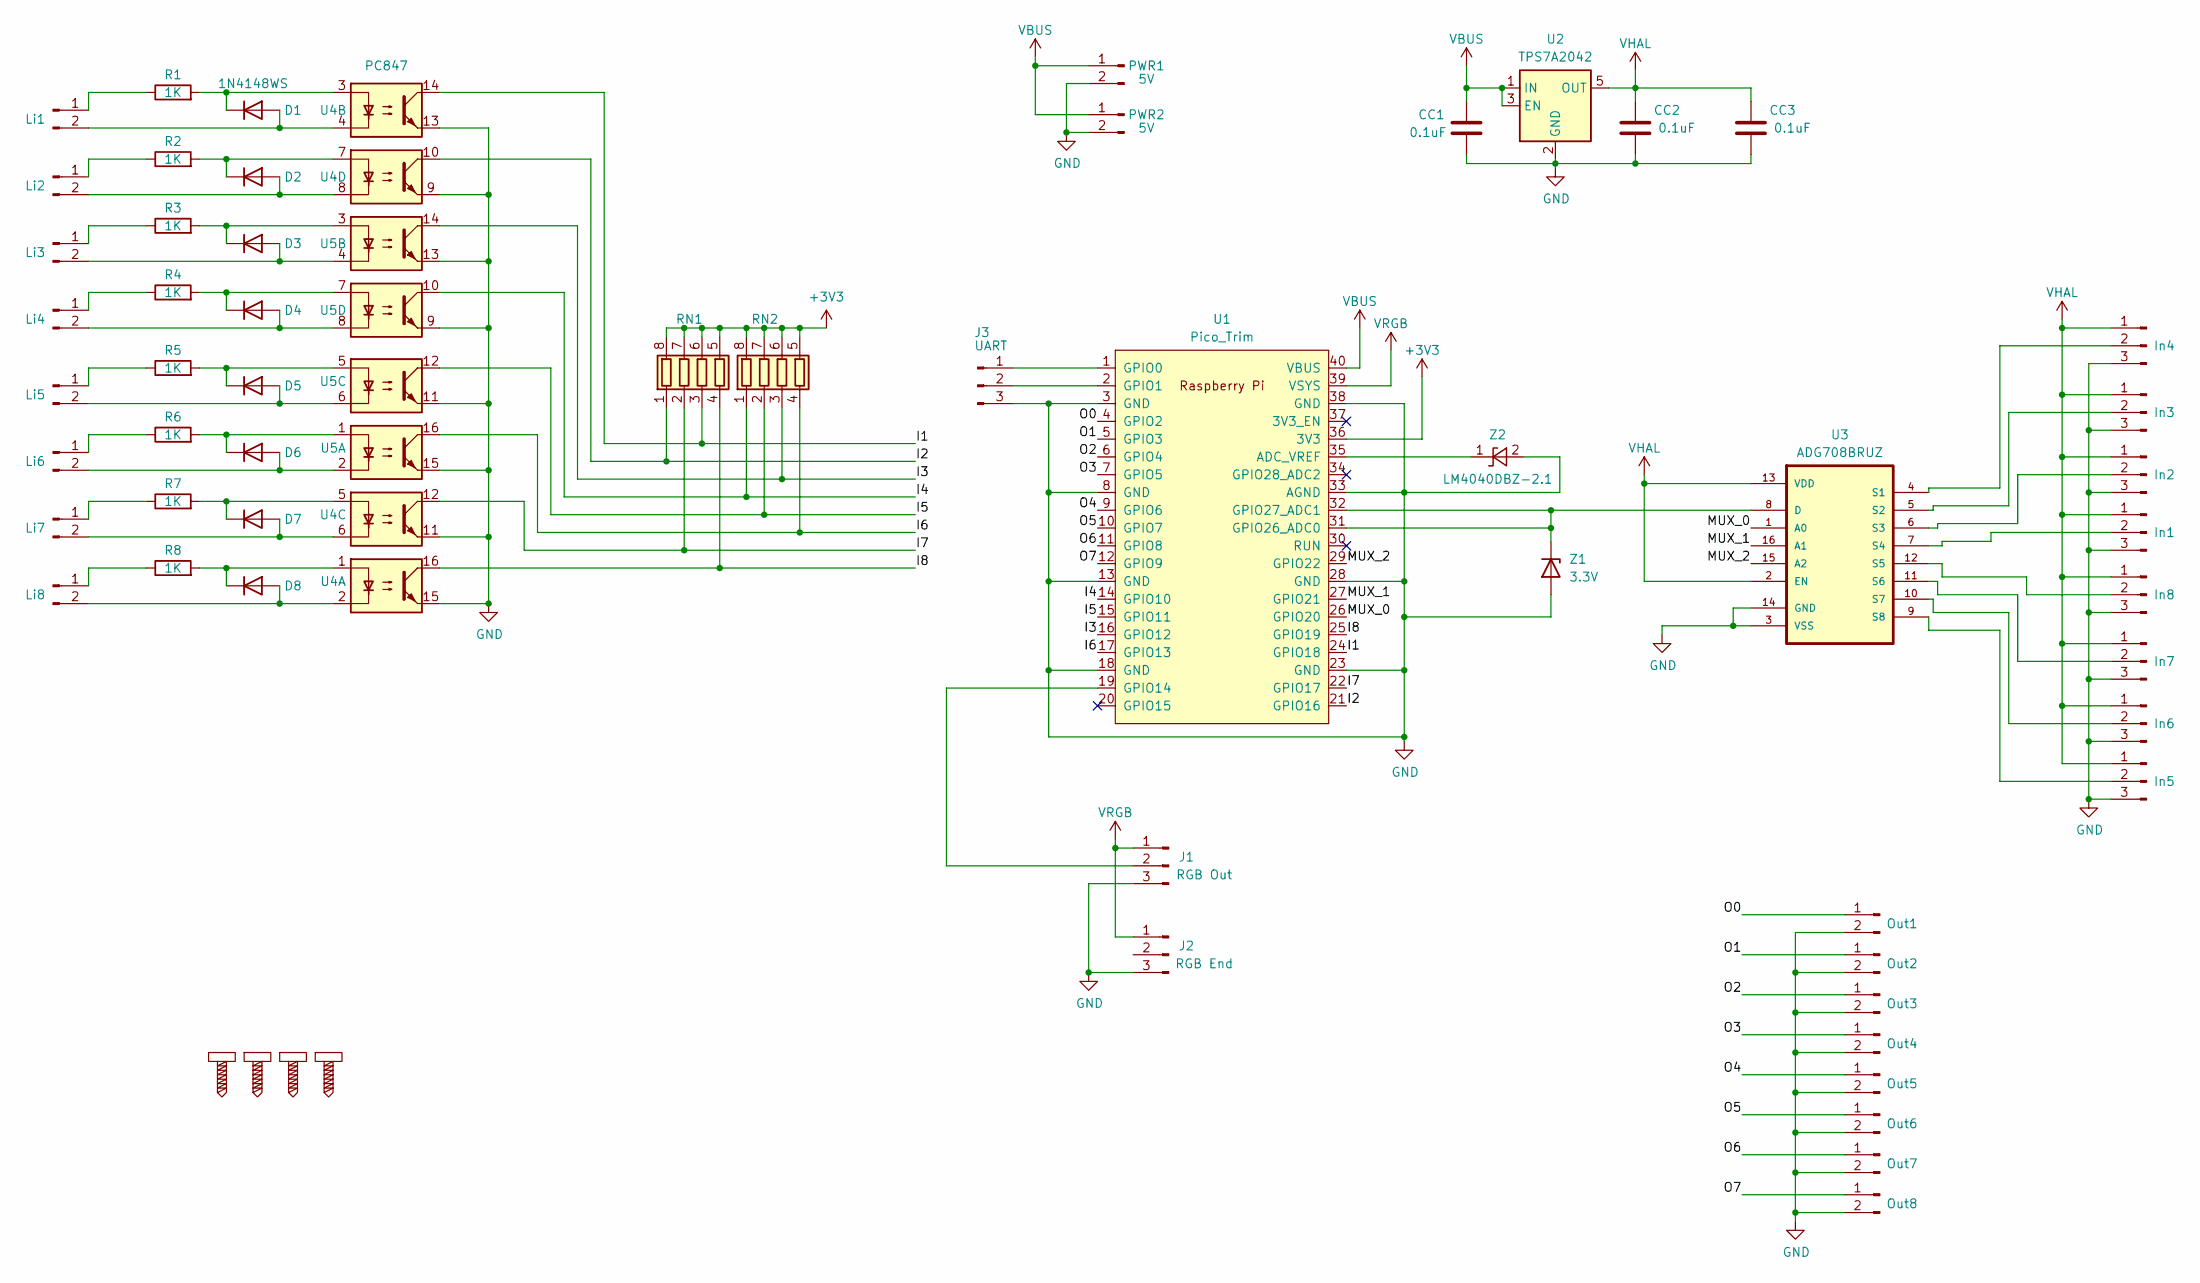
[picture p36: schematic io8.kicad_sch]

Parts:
CC1, CC2, CC3: 0.1uF; C_0603_1608Metric_Pad1.08x0.95mm_HandSolder
D1, D2, D3, D4, D5, D6, D7, D8: 1N4148WS; D_SOD-323_FAT
In1, In2, In3, In4, In5, In6, In7, In8: Conn_01x03_Pin; SH1.0_3P_Solder_Combo
J1: RGB Out; SH1.0_3P_Solder_Combo
J2: RGB End; SH1.0_3P_Solder_Combo
J3: UART; JST_XH_B3B-XH-A_1x03_P2.50mm_Vertical
Li1, Li2, Li3, Li4, Li5, Li6, Li7, Li8: Conn_01x02_Pin; JST_XH_B2B-XH-A_1x02_P2.50mm_Vertical
Out1, Out2, Out3, Out4, Out5, Out6, Out7, Out8: Conn_01x02_Pin; JST_XH_B2B-XH-A_1x02_P2.50mm_Vertical
PWR1, PWR2: 5V; JST_XH_B2B-XH-A_1x02_P2.50mm_Vertical
R1, R2, R3, R4, R5, R6, R7, R8: 1K; R_0805_2012Metric_Pad1.20x1.40mm_HandSolder
RN1, RN2: R_Pack04; R_Array_Convex_4x0805
S1, S2, S3, S4: M3_Screw
U1: Pico_Trim; RPi_Pico_SMD_No_USB
U2: TPS7A2042; SOT-23-5
U3: ADG708BRUZ; TSSOP-16_4.4x5mm_P0.65mm
U4, U5: PC847; SOP-16_4.4x10.4mm_P1.27mm
Z1: 3.3V; D_SOD-123F
Z2: LM4040DBZ-2.1; SOT-23-FAT

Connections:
+3V3: RN1.5 (R4.2), RN1.6 (R3.2), RN1.7 (R2.2), RN1.8 (R1.2), RN2.5 (R4.2), RN2.6 (R3.2), RN2.7 (R2.2), RN2.8 (R1.2), U1.36 (3V3)
/I1: RN1.3 (R3.1), U1.24 (GPIO18), U4.14
/I2: RN1.1 (R1.1), U1.21 (GPIO16), U4.10
/I3: RN2.3 (R3.1), U1.16 (GPIO12), U5.14
/I4: RN2.1 (R1.1), U1.14 (GPIO10), U5.10
/I5: RN2.2 (R2.1), U1.15 (GPIO11), U5.12
/I6: RN2.4 (R4.1), U1.17 (GPIO13), U5.16
/I7: RN1.2 (R2.1), U1.22 (GPIO17), U4.12
/I8: RN1.4 (R4.1), U1.25 (GPIO19), U4.16
/MUX_0: U1.26 (GPIO20), U3.1 (A0)
/MUX_1: U1.27 (GPIO21), U3.16 (A1)
/MUX_2: U1.29 (GPIO22), U3.15 (A2)
/O0: Out1.1, U1.4 (GPIO2)
/O1: Out2.1, U1.5 (GPIO3)
/O2: Out3.1, U1.6 (GPIO4)
/O3: Out4.1, U1.7 (GPIO5)
/O4: Out5.1, U1.9 (GPIO6)
/O5: Out6.1, U1.10 (GPIO7)
/O6: Out7.1, U1.11 (GPIO8)
/O7: Out8.1, U1.12 (GPIO9)
GND: CC1.2, CC2.2, CC3.2, In1.3, In2.3, In3.3, In4.3, In5.3, In6.3, In7.3, In8.3, J1.3, J2.3, J3.3, Out1.2, Out2.2, Out3.2, Out4.2, Out5.2, Out6.2, Out7.2, Out8.2, PWR1.2, PWR2.2, U1.3 (GND), U1.8 (GND), U1.13 (GND), U1.18 (GND), U1.23 (GND), U1.28 (GND), U1.33 (AGND), U1.38 (GND), U2.2 (GND), U3.3 (VSS), U3.14 (GND), U4.9, U4.11, U4.13, U4.15, U5.9, U5.11, U5.13, U5.15, Z1.2 (A), Z2.2 (A)
unnamed: D1.2 (A), Li1.2, U4.4
unnamed: D1.1 (K), R1.2, U4.3
unnamed: D2.2 (A), Li2.2, U4.8
unnamed: D2.1 (K), R2.2, U4.7
unnamed: D3.2 (A), Li3.2, U5.4
unnamed: D3.1 (K), R3.2, U5.3
unnamed: D4.2 (A), Li4.2, U5.8
unnamed: D4.1 (K), R4.2, U5.7
unnamed: D5.2 (A), Li5.2, U5.6
unnamed: D5.1 (K), R5.2, U5.5
unnamed: D6.2 (A), Li6.2, U5.2
unnamed: D6.1 (K), R6.2, U5.1
unnamed: D7.2 (A), Li7.2, U4.6
unnamed: D7.1 (K), R7.2, U4.5
unnamed: D8.2 (A), Li8.2, U4.2
unnamed: D8.1 (K), R8.2, U4.1
unnamed: In1.2, U3.7 (S4)
unnamed: In2.2, U3.6 (S3)
unnamed: In3.2, U3.5 (S2)
unnamed: In4.2, U3.4 (S1)
unnamed: In5.2, U3.9 (S8)
unnamed: In6.2, U3.10 (S7)
unnamed: In7.2, U3.11 (S6)
unnamed: In8.2, U3.12 (S5)
unnamed: J1.2, U1.19 (GPIO14)
unnamed: J3.1, U1.1 (GPIO0)
unnamed: J3.2, U1.2 (GPIO1)
unnamed: Li1.1, R1.1
unnamed: Li2.1, R2.1
unnamed: Li3.1, R3.1
unnamed: Li4.1, R4.1
unnamed: Li5.1, R5.1
unnamed: Li6.1, R6.1
unnamed: Li7.1, R7.1
unnamed: Li8.1, R8.1
unnamed: U1.35 (ADC_VREF), Z2.1 (K)
unnamed: U1.31 (GPIO26_ADC0), U1.32 (GPIO27_ADC1), U3.8 (D), Z1.1 (K)
VBUS: CC1.1, PWR1.1, PWR2.1, U1.40 (VBUS), U2.1 (IN), U2.3 (EN)
VHAL: CC2.1, CC3.1, In1.1, In2.1, In3.1, In4.1, In5.1, In6.1, In7.1, In8.1, U2.5 (OUT), U3.2 (EN), U3.13 (VDD)
VRGB: J1.1, J2.1, U1.39 (VSYS)

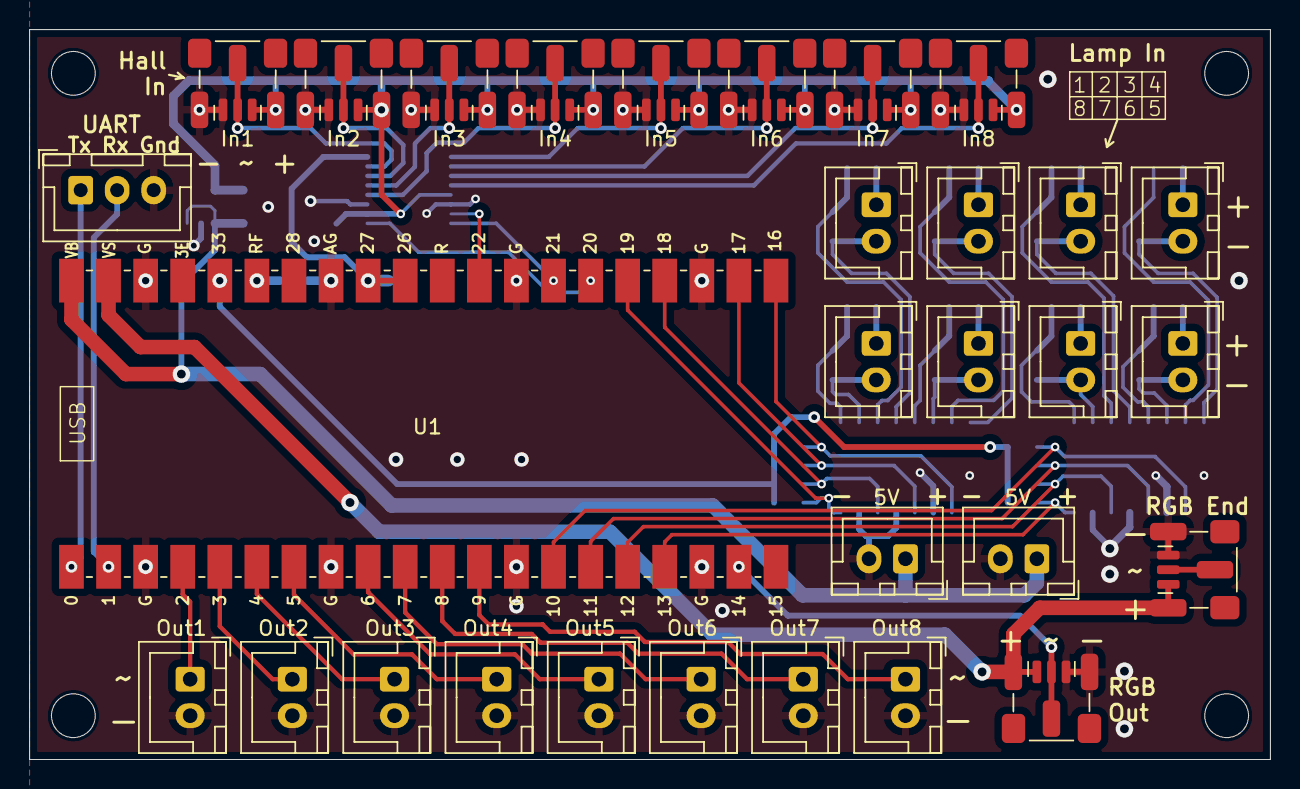
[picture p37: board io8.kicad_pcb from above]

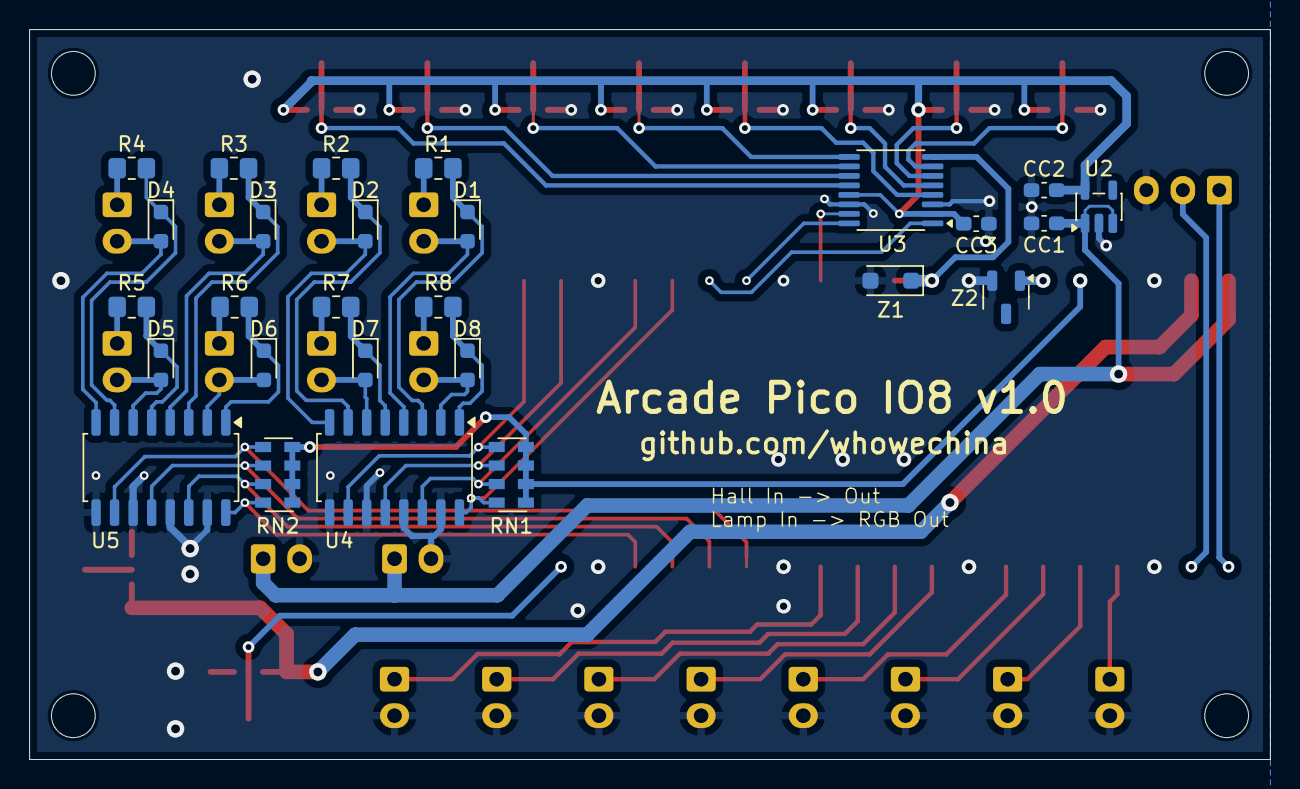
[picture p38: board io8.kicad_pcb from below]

Board: 2 copper layers, 85.0 x 50.0 mm, 61 parts (27 on the bottom side), 61 nets.

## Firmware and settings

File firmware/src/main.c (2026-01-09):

/*
 * Controller Main
 * WHowe <github.com/whowechina>
 */

#include <stdlib.h>
#include <stdint.h>
#include <stdbool.h>

#include "pico/stdio.h"
#include "pico/stdlib.h"
#include "bsp/board.h"
#include "pico/multicore.h"
#include "pico/bootrom.h"

#include "hardware/gpio.h"
#include "hardware/sync.h"
#include "hardware/structs/ioqspi.h"
#include "hardware/structs/sio.h"

#include "tusb.h"
#include "usb_descriptors.h"

#include "board_defs.h"

#include "save.h"
#include "config.h"
#include "cli.h"
#include "commands.h"

#include "light.h"
#include "button.h"
#include "hebtn.h"
#include "output.h"

static void run_lights()
{
    for (int i = 0; i < 8; i++) {
        uint32_t color = rgb32_from_hsv(i * 31, 255, 255);
        light_set(i, color, false);
    }
}

static mutex_t core1_io_lock;
static void core1_loop()
{
    while (1) {
        if (mutex_try_enter(&core1_io_lock, NULL)) {
            run_lights();
            light_update();
            mutex_exit(&core1_io_lock);
        }
        cli_fps_count(1);
        sleep_us(700);
    }
}

struct __attribute__((packed)) {
    uint8_t buttons;
    uint8_t padding;
} hid_report, hid_report_sent;

static void hid_update()
{
    uint32_t buttons = button_read() ^ 0xffc; // invert the fader bits

    hid_report.buttons = buttons << 12;
    for (int i = 0; i < 12; i++) {
        if (hebtn_actuated(i)) {
            hid_report.buttons |= (1 << i);
        }
    }

    static uint64_t last_report_time = 0;
    if (tud_hid_ready()) {
        uint64_t now = time_us_64();
        if ((memcmp(&hid_report, &hid_report_sent, sizeof(hid_report)) == 0) &&
            (now - last_report_time < 10000)) {
            return;
        }
        last_report_time = now;
        if (tud_hid_report(REPORT_ID_JOYSTICK, &hid_report, sizeof(hid_report))) {
            hid_report_sent = hid_report;
        }
    }
}

static void debug_display()
{
    static uint64_t last_display = 0;
    uint64_t now = time_us_64();
    if (now - last_display < 100000) {
        return;
    }
    last_display = now;
}

static void bridge_ctrl()
{
    for (int i = 0; i < output_num(); i++) {
        bool active = hebtn_actuated(i);
        int route = arcade_cfg->route.output[i] % 8;
        output_set(route, !active);
    }

    uint16_t light_input = button_read();
    static uint16_t last_light_input = 0;
    if (light_input != last_light_input) {
        if (arcade_runtime.debug.input) {
            printf("Input: 0x%04x\n", light_input);
        }
        last_light_input = light_input;
    }

    for (int i = 0; i < button_num(); i++) {
        bool active = (light_input & (1 << i)) != 0;
        uint32_t color = active ? arcade_cfg->light.color_on[i] : arcade_cfg->light.color_off[i];
        int route = arcade_cfg->route.rgb[i] % 8;
        light_set(route, color, true);
    }
}

static void core0_loop()
{
    uint64_t next_frame = 0;
    while(1) {
        tud_task();

        cli_run();

        save_loop();
        cli_fps_count(0);

        button_update();
        hebtn_update();

        hid_update();
        bridge_ctrl();

        debug_display();
        sleep_until(next_frame);
        next_frame += 1000;
    }
}

/* if certain key pressed when booting, enter update mode */
static void update_check()
{
}

void init()
{
    sleep_ms(50);
    board_init();

    update_check();

    tusb_init();
    stdio_init_all();

    config_init();
    mutex_init(&core1_io_lock);
    save_init(0xca44cdb1, &core1_io_lock);

    light_init();
    button_init();
    hebtn_init(arcade_cfg->calibrated.up, arcade_cfg->calibrated.down,
               arcade_cfg->trigger.on, arcade_cfg->trigger.off);
    output_init();

    cli_init("arcade_pico>", "\n   << Arcade Pico Controller >>\n"
                            " https://github.com/whowechina\n\n");
    
    commands_init();
}

int main(void)
{
    init();
    multicore_launch_core1(core1_loop);
    core0_loop();
    return 0;
}

// Invoked when received GET_REPORT control request
// Application must fill buffer report's content and return its length.
// Return zero will cause the stack to STALL request
uint16_t tud_hid_get_report_cb(uint8_t itf, uint8_t report_id,
                               hid_report_type_t report_type, uint8_t *buffer,
                               uint16_t reqlen)
{
    printf("Get from USB %d-%d\n", report_id, report_type);
    return 0;
}

// Invoked when received SET_REPORT control request or
// received data on OUT endpoint ( Report ID = 0, Type = 0 )
void tud_hid_set_report_cb(uint8_t itf, uint8_t report_id,
                           hid_report_type_t report_type, uint8_t const *buffer,
                           uint16_t bufsize)
{
    if ((report_id == REPORT_ID_LIGHTS) && (bufsize >= 24)) {
        for (int i = 0; i < 8; i++) {
            const uint8_t *rgb = &buffer[i * 3];
            uint32_t color = rgb32(rgb[0], rgb[1], rgb[2], false);
            light_set(i, color, true);
        }
    }
}

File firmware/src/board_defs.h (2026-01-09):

/*
 * Arcade Pico Board Definitions
 * WHowe <github.com/whowechina>
 */

#if defined BOARD_ARCADE_PICO

#define RGB_PIN 14

#define RGB_ORDER GRB // or RGB

#define BUTTON_GPIO { 18, 16, 12, 10, 11, 13, 17, 19  }
#define BUTTON_PULL_UPDOWN { 1, 1, 1, 1, 1, 1, 1, 1 }

#define OUTPUT_GPIO { 2, 3, 4, 5, 6, 7, 8, 9 }
#define OUTPUT_DEFAULT { 1, 1, 1, 1, 1, 1, 1, 1 }

#define HALL_KEY_MUX_ADDRS { 20, 21, 22 }
#define HALL_KEY_MUX_MAP { 3, 2, 1, 0, 7, 6, 5, 4 }
#define HALL_KEY_MUX_EN -1
#define HALL_KEY_ADC_CHN 0

#endif

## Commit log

2025-12-19 Button PCB v1.0
    [Holder - PCB EdgeCut.dxf, LUXEON_3014.stp, SW_Kailh_Choc_V1.stp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]
2025-12-19 IO PCB, progress 50%
    [io.kicad_pcb, io.kicad_sch]
2025-12-26 Button PCB v1.0 rc3
    [Arcade Pico - PCB EdgeCut.dxf, IR908-7C.step, PT908-7C.step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]
2025-12-26 IO Board v1.0 rc0
    [io.kicad_pcb, io.kicad_sch]
2026-01-01 Button and IO8 PCB
    [Arcade Pico - PCB EdgeCut.dxf, HE_PG1353.step, Holder - PCB EdgeCut.dxf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]
2026-01-01 PCB v1.0
2026-01-01 3D print files
    [Chinese.stl, Sanwa_push.stl, Sanwa_twist.stl]
2026-01-02 Better screw clearance
    [button.kicad_pcb]
2026-01-04 PCB version for hotswap
    [Arcade Pico - PCB EdgeCut.dxf, HE_PG1353.step, IR908-7C.step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]
2026-01-04 Remove the abandoned IO PCB
    [io.kicad_pcb, io.kicad_sch]
2026-01-04 Add reference to choc socket
2026-01-09 Clarification on IO board
2026-01-13 Button PCB DIP LED version
    [Arcade Pico - PCB EdgeCut.dxf, HE_PG1353.step, IR908-7C.step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]
2026-01-21 Fix SW1hotswap footprint
    [button.kicad_pcb]
